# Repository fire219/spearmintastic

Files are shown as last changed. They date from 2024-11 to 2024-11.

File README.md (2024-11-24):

# Spearmintastic!
## Self-sufficient, pocket sized
**Spearmintastic** is a pocket-sized device designed for use as Meshtastic node. Unlike most other tiny node designs, it is designed to be fully self sufficient (including battery, solar panel, and LoRa antenna) in a footprint no larger than its 21x71mm PCB.

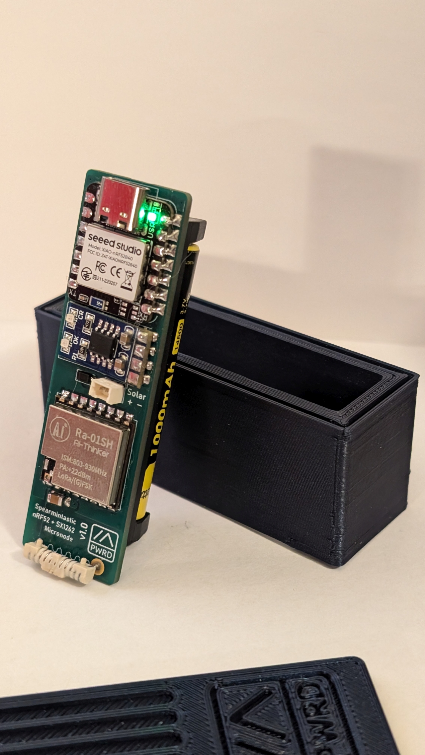
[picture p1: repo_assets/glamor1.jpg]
[](repo_assets/glamor1full.jpg)
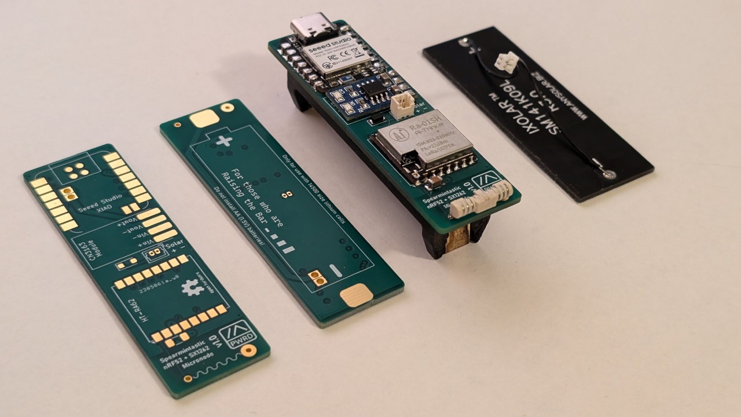
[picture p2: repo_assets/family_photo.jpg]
[](repo_assets/family_photofull.jpg)

**Spearmintastic** uses a "14500" (AA) size protected Li-ion battery, minimizing fears about sketchy pouch cells from Amazon or AliExpress. These can be found via online retailers as "flashlight batteries".

## Errata Notes:

- Solar polarity silkscreen is reversed on v1.0 board
- Protected 14500 lithium cells tend to be a couple millimeters longer than a "normal" AA battery. You may need to do some modifications to the Keystone holder to make the battery fit well. If needed, recommended modifications are to flatten the contact springs with a pair of pliers, as well as cutting some of the plastic "backstop" out from behind the positive contact to allow it more travel.

## Bill Of Materials

| Part | Spec | Qty | Link |
|--|--|--|--|
| PCB | Spearmintastic v1.0 | 1 | This repository! |
| Microcontroller | Seeed Studio XIAO nRF52840 | 1 | [DigiKey](https://www.digikey.com/en/products/detail/seeed-technology-co-ltd/102010448/16652893) |
| LoRa Radio | Ai-Thinker Ra-01SH ***or*** Heltec HT-RA62 | 1 | [Ra-01SH](https://www.aliexpress.us/item/3256802374880132.html) or [HT-RA62](https://www.aliexpress.us/item/3256805259034353.html) |
| Solar Charger | SD05CRMA (CN3163 Breakout) | 1 | [AliExpress](https://www.aliexpress.us/item/3256805359874309.html) |
| Antenna | Pulse W3139 | 1 | [DigiKey](https://www.digikey.com/en/products/detail/pulse-electronics/W3139/9817201) |
| Solar Panel | ANYSOLAR SM141K09L | 1 | [DigiKey](https://www.digikey.com/en/products/detail/anysolar-ltd/SM141K09L/9990465) |
| Solar Panel Pigtail | 2x wire, 1.25mm PicoBlade termination | 1 | [DigiKey](https://www.digikey.com/en/products/detail/molex/0151340200/6198138) |
| Solar Panel Connector | 2 position 1.25mm PicoBlade, vertical THT | 1 | [DigiKey](https://www.digikey.com/en/products/detail/molex/0530470210/242853)
| Solar Overvoltage Shunt | 6.2V Zener Diode (SOD123 package) | 1 | [DigiKey](https://www.digikey.com/en/products/detail/micro-commercial-co/MMSZ4691-TP/2345540) |
| Bulk Capacitor | 10uF MLCC capacitor (1206 package) | 1 | [DigiKey](https://www.digikey.com/en/products/detail/samsung-electro-mechanics/CL31A106MAHNNNE/3886839) | 
| Battery Holder | Keystone 1024 *(see note)* | 1 | [DigiKey](https://www.digikey.com/en/products/detail/keystone-electronics/1024/2178268) |
| Battery | 14500 size Li-Ion cell (protected) | 1 | [B&H Photo](https://www.bhphotovideo.com/c/product/1811929-REG/nitecore_nl1410_14500_li_ion_rechargeable.html) |
| Case *(optional)* | Spearmintastic case | 1 | Your 3D printer (files on this repo)

## Case
A 3D printable case has been designed to fit a fully assembled Spearmintastic, with battery and panel. A cutout is provided for access to the Xiao's USB-C port.

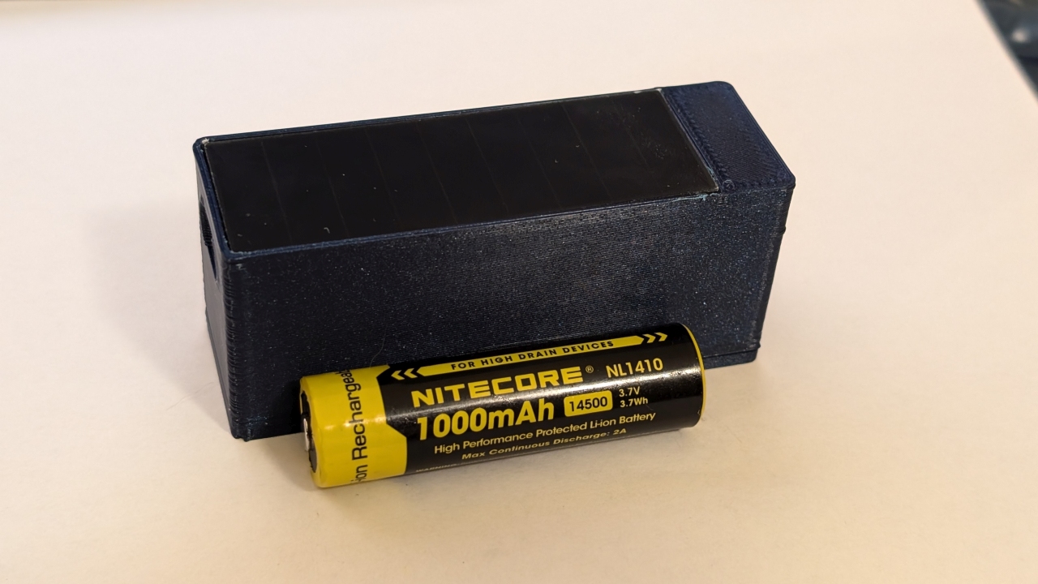
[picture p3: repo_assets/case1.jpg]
[](repo_assets/case1full.jpg)
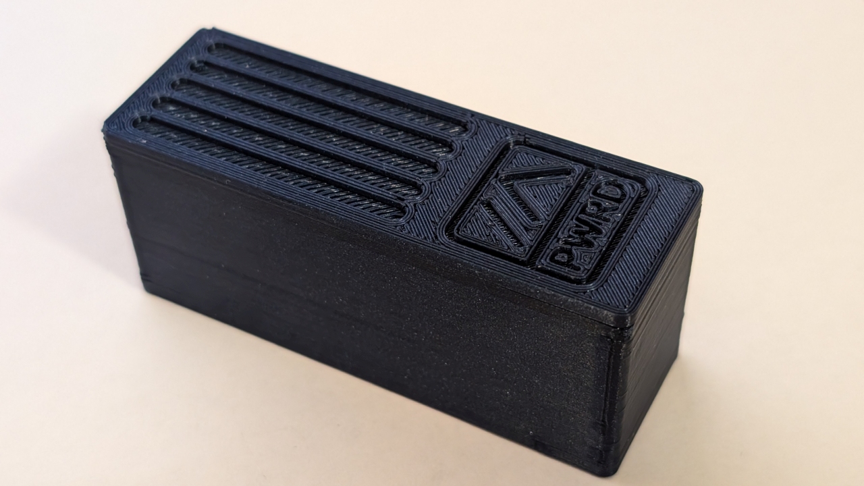
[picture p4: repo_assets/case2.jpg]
[](repo_assets/case2full.jpg)

## Firmware
*Pre-built firmware coming soon?*

Meshtastic built for the "xiao_ble" target should be directly compatible with Spearmintastic, however in my testing, the battery voltage indication does not work. This can be fixed by adding the following to the *variant.cpp* file:

    void initVariant() {
	    pinMode(BAT_READ, OUTPUT);
	    digitalWrite(BAT_READ, LOW);
    }
This is not an issue specific to Spearmintastic, as the voltage monitoring circuit is built onto the Xiao.

## License

**Spearmintastic** is licensed under the CERN OHL v2 Permissive license. See the *LICENSE* file for more information.

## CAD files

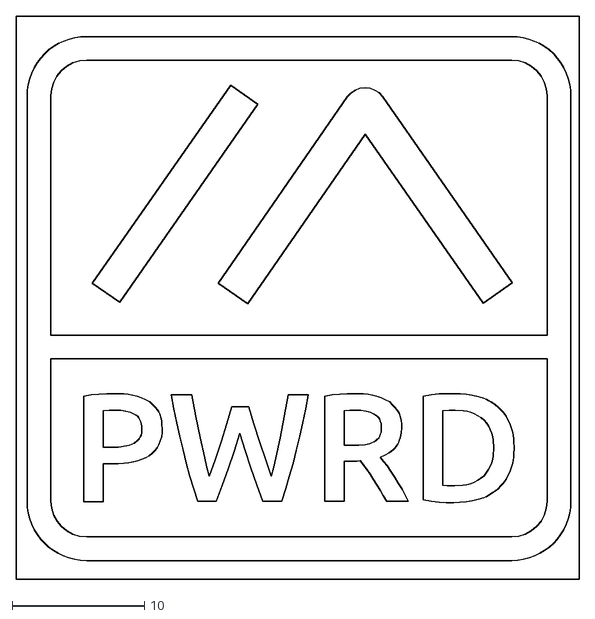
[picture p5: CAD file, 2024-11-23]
spearmintastic case/m_pwrd.dxf
42.5 x 42.5

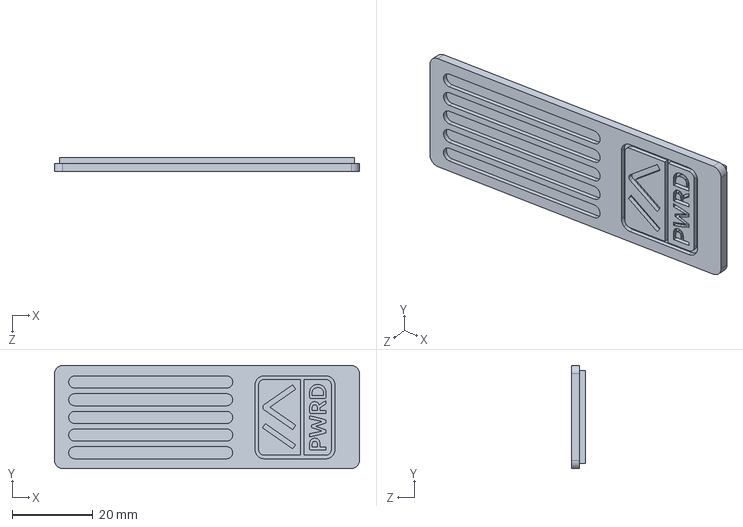
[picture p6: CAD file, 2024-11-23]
spearmintastic case/SPRMNT case lid.SLDPRT
75.5 x 25.5 x 3.50 mm

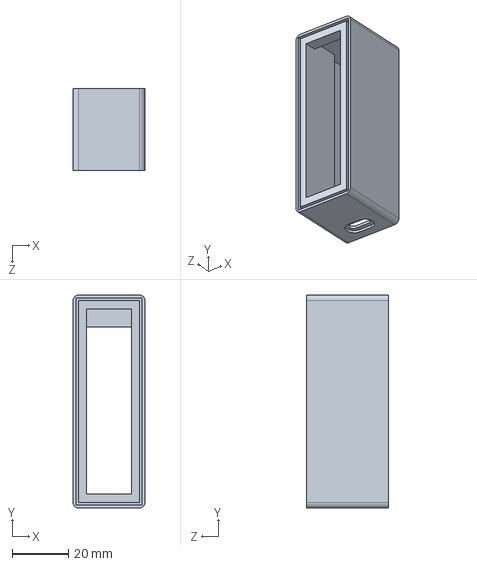
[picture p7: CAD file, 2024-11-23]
spearmintastic case/SPRMT case body.SLDPRT
25.5 x 75.5 x 29.0 mm

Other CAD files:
spearmintastic case/SPRMNT case lid.STL
spearmintastic case/SPRMT case body.STL

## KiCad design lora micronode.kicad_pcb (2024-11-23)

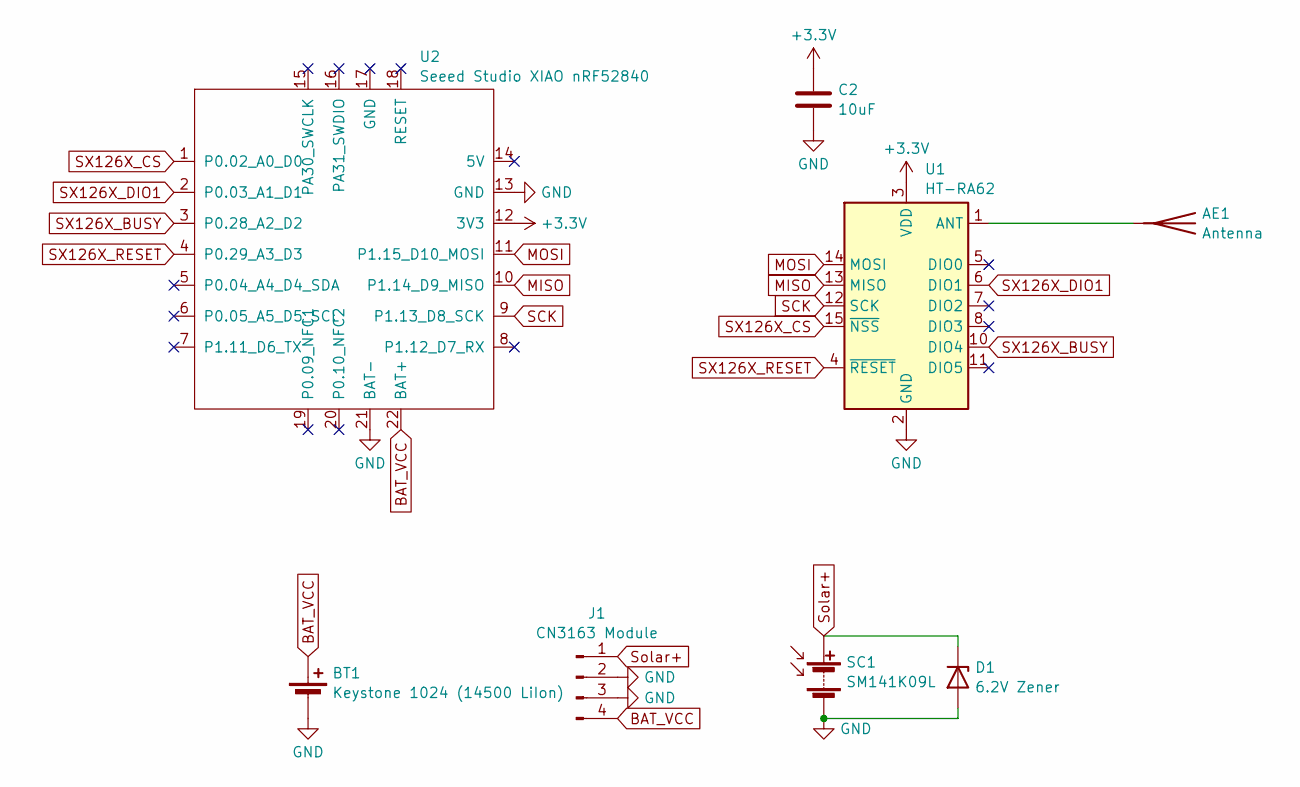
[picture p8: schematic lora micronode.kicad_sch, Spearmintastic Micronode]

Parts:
AE1: Antenna; 18mm-Antenna-THT
BT1: Keystone 1024 (14500 LiIon); Keystone_1024_SMD_14500
C2: 10uF; C_1206_3216Metric_Pad1.33x1.80mm_HandSolder
D1: 6.2V Zener; D_SOD-123F
J1: CN3163 Module; CN3163_Module
SC1: SM141K09L; Molex_PicoBlade_53047-0210_1x02_P1.25mm_Vertical
U1: HT-RA62; Ai-Thinker-Ra-01-LoRa
U2: Seeed Studio XIAO nRF52840; XIAO-nRF-THT_batt

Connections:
+3.3V: C2.1, U1.3 (VDD), U2.12 (3V3)
BAT_VCC: BT1.1 (+), J1.4, U2.22 (BAT+)
GND: BT1.2 (-), C2.2, D1.2 (A), J1.2, J1.3, SC1.2 (-), U1.2 (GND), U1.9 (GND), U1.16 (GND), U2.13 (GND), U2.21 (BAT-)
MISO: U1.13 (MISO), U2.10 (P1.14_D9_MISO)
MOSI: U1.14 (MOSI), U2.11 (P1.15_D10_MOSI)
unnamed: AE1.1 (A), U1.1 (ANT)
SCK: U1.12 (SCK), U2.9 (P1.13_D8_SCK)
SX126X_BUSY: U1.10 (DIO4), U2.3 (P0.28_A2_D2)
SX126X_CS: U1.15 (~NSS), U2.1 (P0.02_A0_D0)
SX126X_DIO1: U1.6 (DIO1), U2.2 (P0.03_A1_D1)
SX126X_RESET: U1.4 (~RESET), U2.4 (P0.29_A3_D3)
Solar+: D1.1 (K), J1.1, SC1.1 (+)

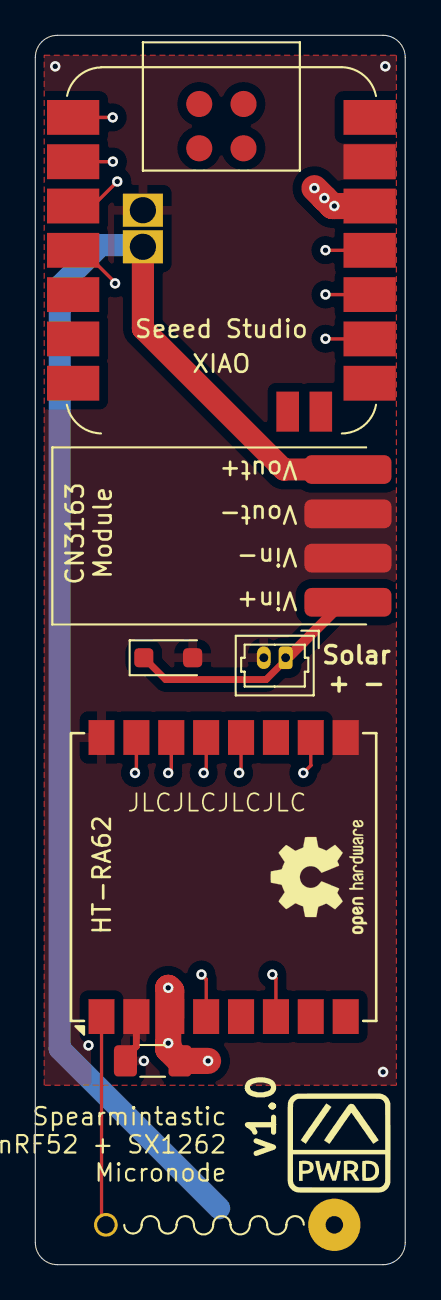
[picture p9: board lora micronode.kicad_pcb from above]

Board: 4 copper layers, 21.2 x 70.5 mm, 9 parts (1 on the bottom side), 12 nets.

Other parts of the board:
.: LOGO; m_powered
